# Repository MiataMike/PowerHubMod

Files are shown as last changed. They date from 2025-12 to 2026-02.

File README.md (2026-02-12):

# PowerHubModule
Simple fused digital switching

## Git contents
Design files: 
-- Schematic
-- Fusion360 native project files
-- 3D model .obj
-- electrical library for custom parts
-- Dimensional drawing

Manufacturing files:
-- Gerbers for PCB fab
-- BOM for ordering from Digikey

## Electrical Specifications
Input voltage range: 2.5-20V
Maxiumum output voltage limit: 80V
Gate capacitance: 4.5uF max

Connect multiple modules together with a bus bar for a custom fusebox. Ground the control pin to turn on, or bypass the MOSFET with 14awg wire for constant power

For trouble-free operation, it is highly recommended that you protect the Module's FET with a TVS diode like MPN: TP6KE22A or SM30T18AY

Inductive loads like relays without flyback diodes can cause damaging voltage spikes when shut off 

## Future ideas
Increase pad size for easier soldering (COMPLETE)

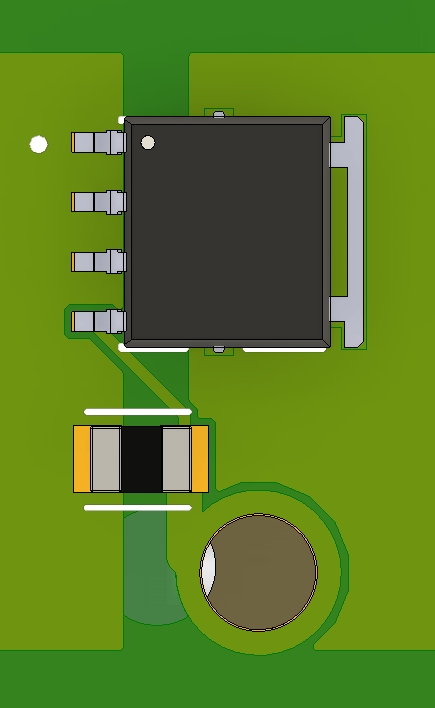
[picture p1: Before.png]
Before

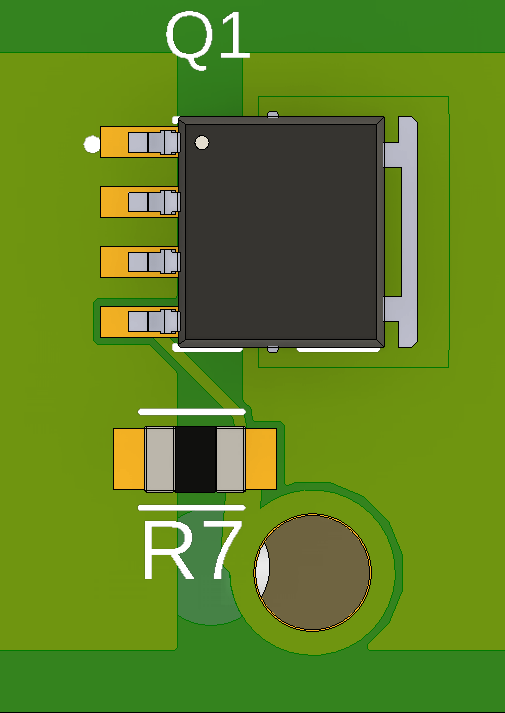
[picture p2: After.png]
After


Built-in slew rate limiting resistor on gate
Locking/secure connector for gate control line
Built-in TVS w/ parallel ground bus bar

## Contact info
Author: Michael Turner
Email: me@Michael-Turner.ee
License:
This project is licensed under the CERN Open Hardware License v2 – Strongly Reciprocal (CERN-OHL-S).

You are free to use, modify, and manufacture this design, provided that any distributed modifications
are released under the same license.

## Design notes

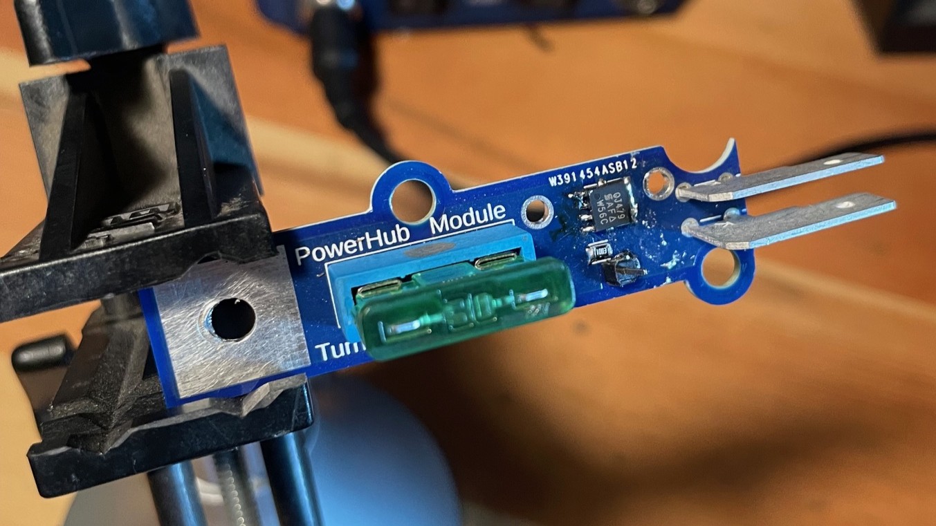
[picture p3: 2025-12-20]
ModulePicture.jpg

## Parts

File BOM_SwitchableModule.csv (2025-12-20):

Index | DigiKey Part # | Manufacturer Part Number | Manufacturer | Description | Customer Reference | Quantity | Backorder | Unit Price | Extended Price
1 | 36-3557-15-ND | 3557-15 | Keystone Electronics | FUSE HOLDER BLADE 30A PCB |  | 1 | 0 | $1.21000 | $2.42
2 | 36-1266-ND | 1266 | Keystone Electronics | CONN QC TAB 0.250 SOLDER |  | 2 | 0 | $0.22200 | $3.33
3 | SQJ479EP-T1_GE3CT-ND | SQJ479EP-T1_GE3 | Vishay Siliconix | MOSFET P-CH 80V 32A PPAK SO-8 |  | 1 | 0 | $1.12500 | $11.25
4 | 311-100KCRCT-ND | RC0805FR-07100KL | YAGEO | RES 100K OHM 1% 1/8W 0805 |  | 1 | 0 | $0.02240 | $0.56
 |  |  |  |  |  |  |  | Subtotal | $3.12

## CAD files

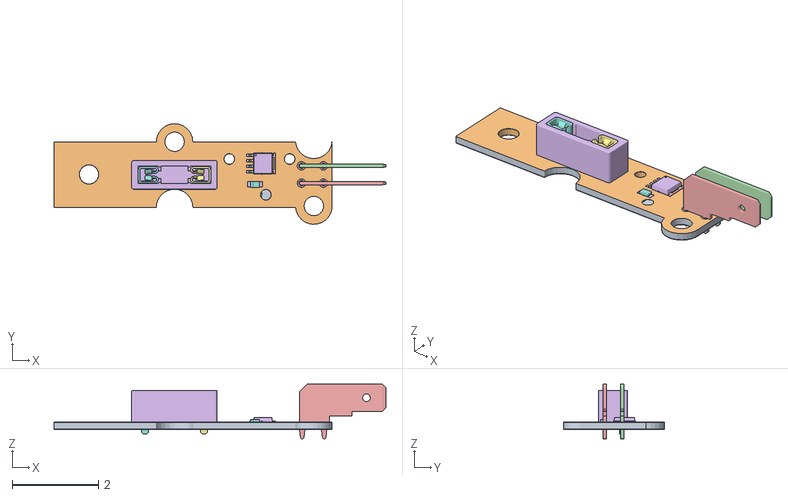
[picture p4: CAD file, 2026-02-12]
SwitchableModule.obj
7.69 x 2.33 x 1.27
Board
CopperHoles

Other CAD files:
SwitchableModule.f3d
SwitchableModule.f3z

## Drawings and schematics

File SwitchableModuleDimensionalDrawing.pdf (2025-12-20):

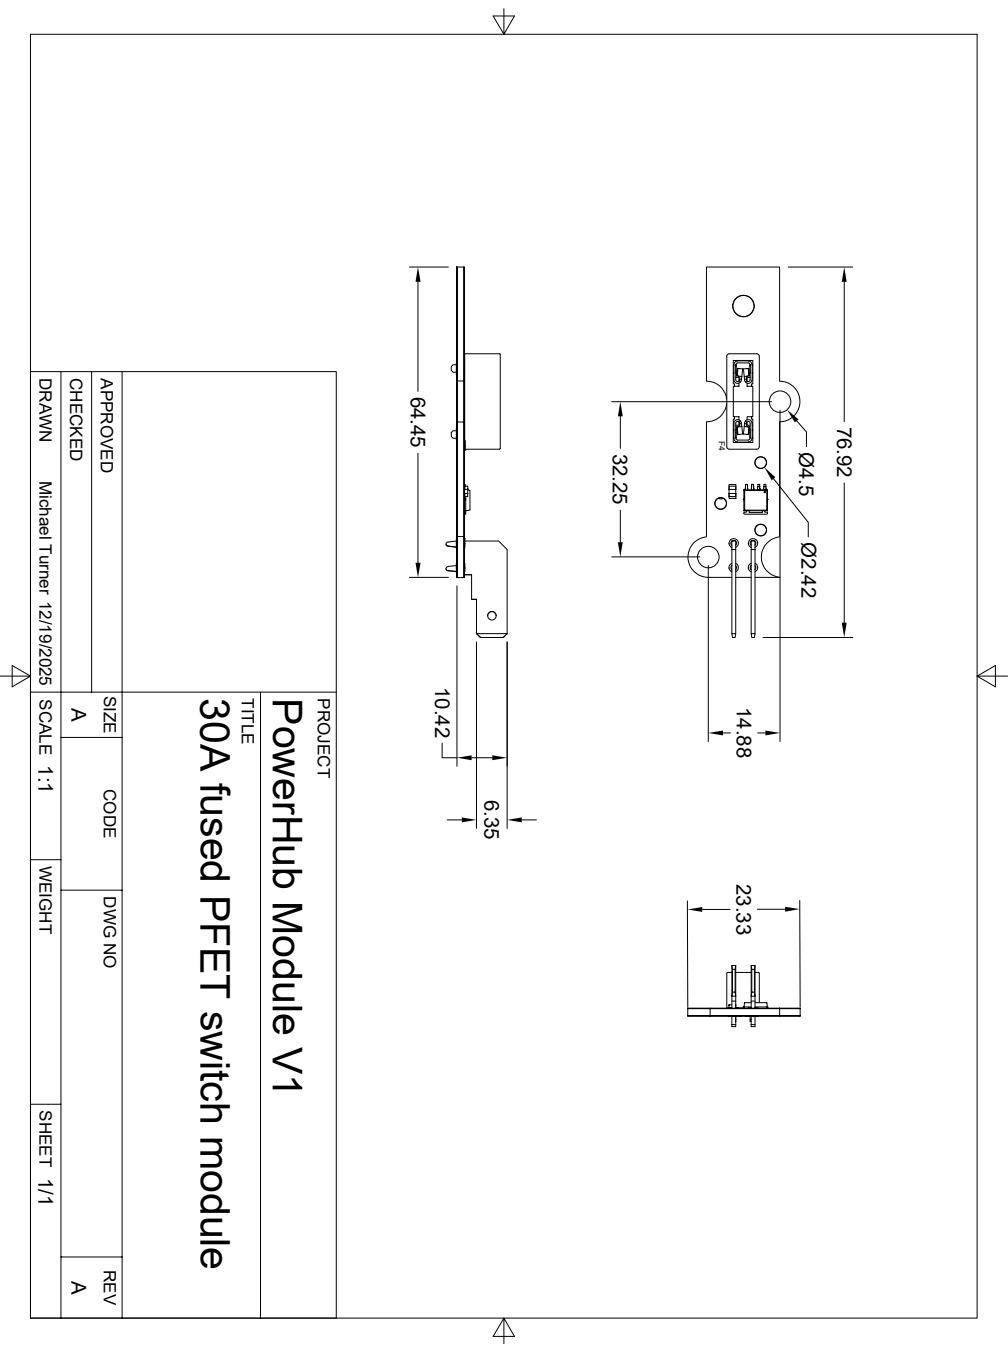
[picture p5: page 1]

F4 TITLE PROJECT DRAWN CHECKED APPROVED SCALE WEIGHT SHEET DWG NO REV CODE SIZE 1/1 1:1 12/19/2025 Michael Turner A A 30A fused PFET switch module PowerHub Module V1 76.9232.25 14.88 Ø4.5 Ø2.42 23.33 10.42 64.45 6.35

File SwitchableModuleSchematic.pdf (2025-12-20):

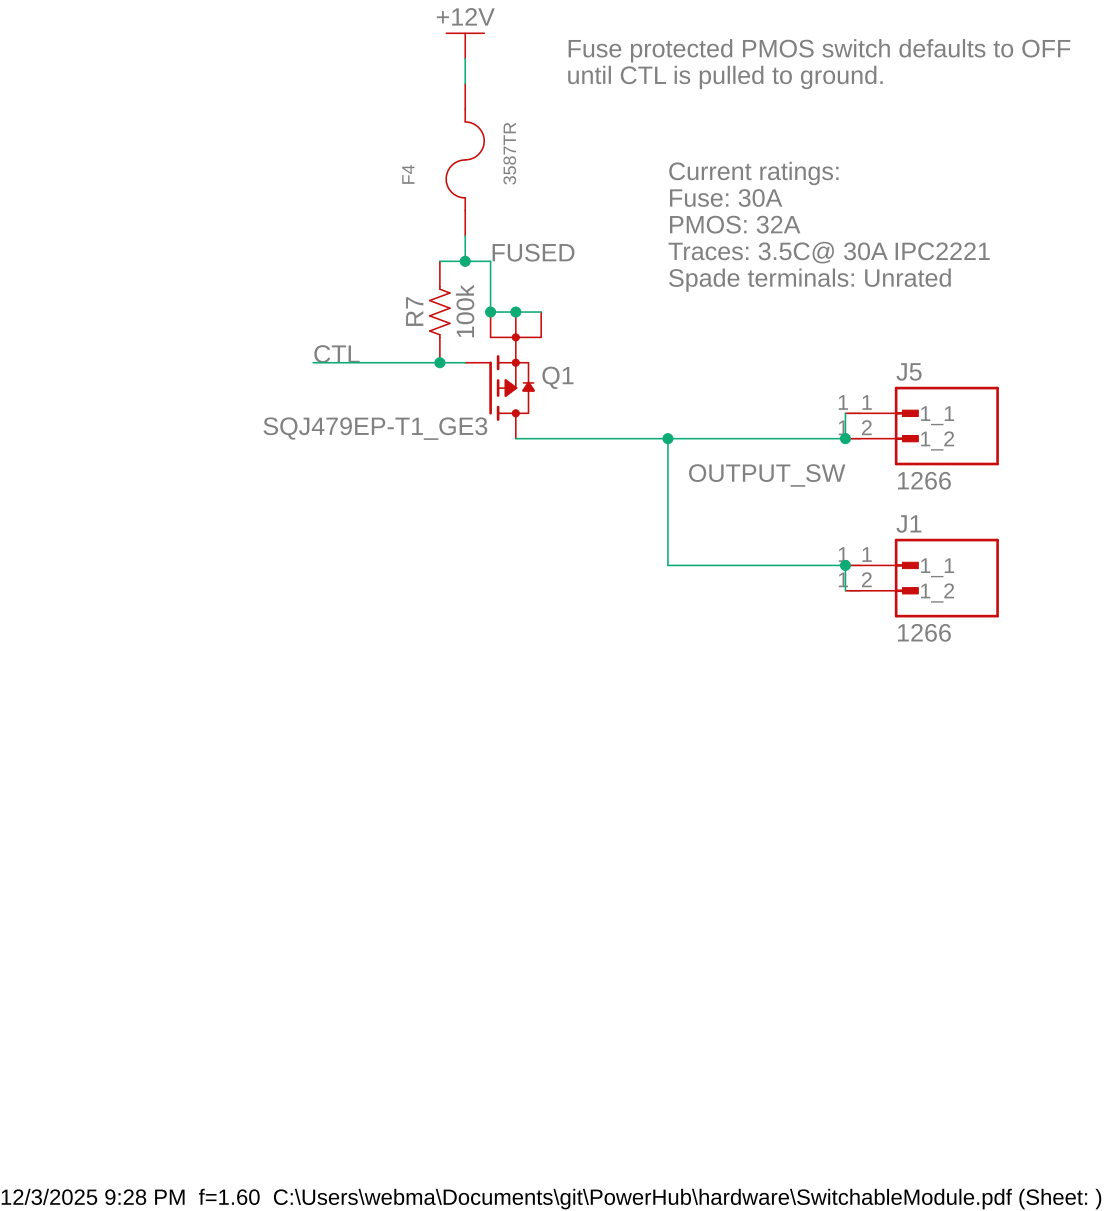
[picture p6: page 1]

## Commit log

2025-12-20 PowerHubMod V1
    First board run of the prototype custom fusebox system. Includes standard file package
    [BOM_SwitchableModule.csv, SwitchableModule.f3d, SwitchableModule.f3z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]
2026-02-12 Updated footprints for easier hand soldering
    [SwitchableModule.f3d, SwitchableModule.f3z, SwitchableModule.obj]
